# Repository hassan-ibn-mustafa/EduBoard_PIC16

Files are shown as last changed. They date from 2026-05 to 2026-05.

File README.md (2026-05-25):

# EduBoard PIC16 - Trainer Kit

An educational, single-layer development board designed to simplify learning and prototyping with the Microchip PIC16F877A microcontroller. Designed entirely in KiCad, this board eliminates complexity and focuses on a modular, jumper-based routing architecture for students and electronics enthusiasts.

## 🔗 Live Interactive Preview
    
🌐 **[Click Here to View Live-Demo_&_Interactive_BOM & Project Website](https://hassan-ibn-mustafa.github.io/EduBoard_PIC16/)**

*Click the badge above to explore the live interactive web deployment and view the full layout directly in your browser!*

## 🗺️ Circuit Schematic

Here is the complete schematic diagram of the EduBoard PIC16. For a high-resolution scalable version, please check the `Docs/` directory.

<div align="center">
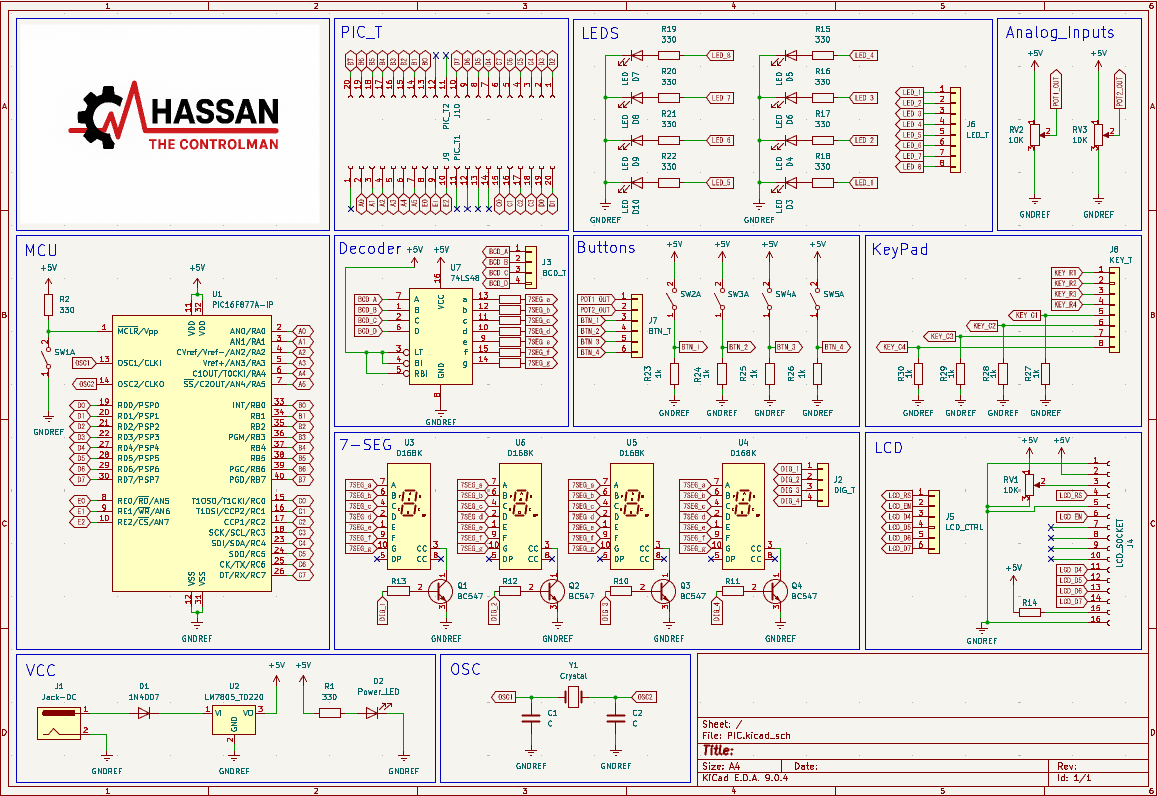
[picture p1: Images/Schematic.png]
EduBoard PIC16 Schematic Diagram
  
</div>

## 📸 3D Hardware Showcase

<div align="center">
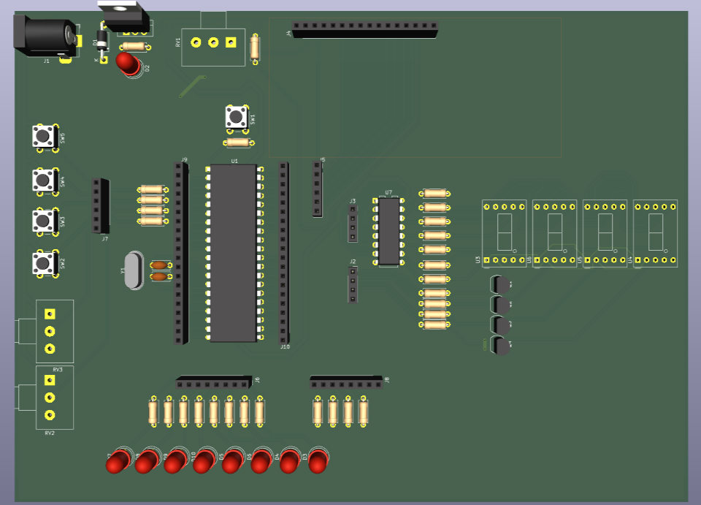
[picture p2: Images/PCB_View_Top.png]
PCB Top View
  
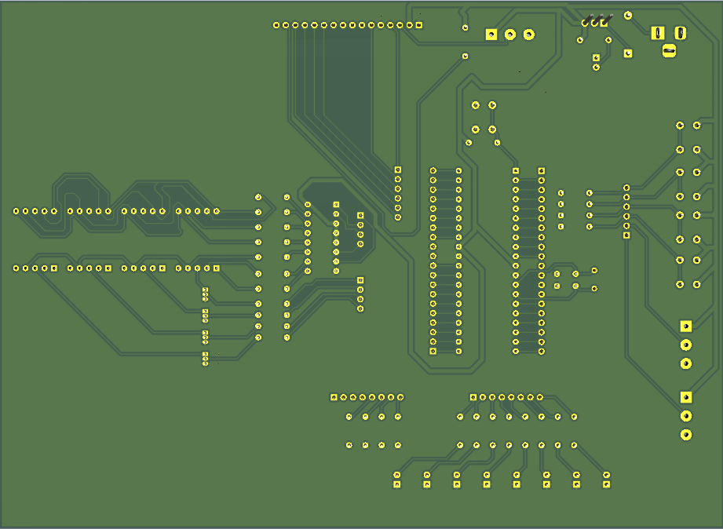
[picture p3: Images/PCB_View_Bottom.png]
PCB Bottom View
  
</div>

## 📁 Repository Structure

The repository is organized to provide easy access to documentation, source files, and manufacturing data:

* **`Docs/`**: Contains easy-to-read PDF files for quick reference without needing CAD software.
  * `Schematic.pdf`
  * `Layout_Top.pdf`
  * `Layout_Bottom.pdf`
* **`Fabrication/`**: Contains the `.zip` file with standard Gerber and Drill files. This zip file is production-ready and can be directly uploaded to any PCB manufacturer (e.g., JLCPCB, PCBWay).
* **`images/`**: Contains 3D renders and physical photos of the board.

## ⚙️ Technical Specifications

* **Microcontroller:** Microchip PIC16F877A
* **PCB Details:** Single-Layer DIY-friendly design
* **EDA Tool:** KiCad
* **Display Peripherals:** 16x2 Character LCD & 4-digit 7-segment display (multiplexed via 74LS48).
* **Power Subsystem:** LM7805 voltage regulation via DC barrel jack.
* **Routing:** 100% jumper-wire configuration using precision female headers for maximum experimental flexibility.

## 🛠️ Fabrication & Manufacturing

To manufacture this board:
1. Navigate to the `Fabrication/` directory.
2. Download the provided `.zip` file.
3. Upload the `.zip` file directly to your preferred PCB manufacturer. No further CAM processing is required.

---
*Designed & Developed by **Hassan Mustafa Hashem** - Industrial Electronics & Control Engineering.*

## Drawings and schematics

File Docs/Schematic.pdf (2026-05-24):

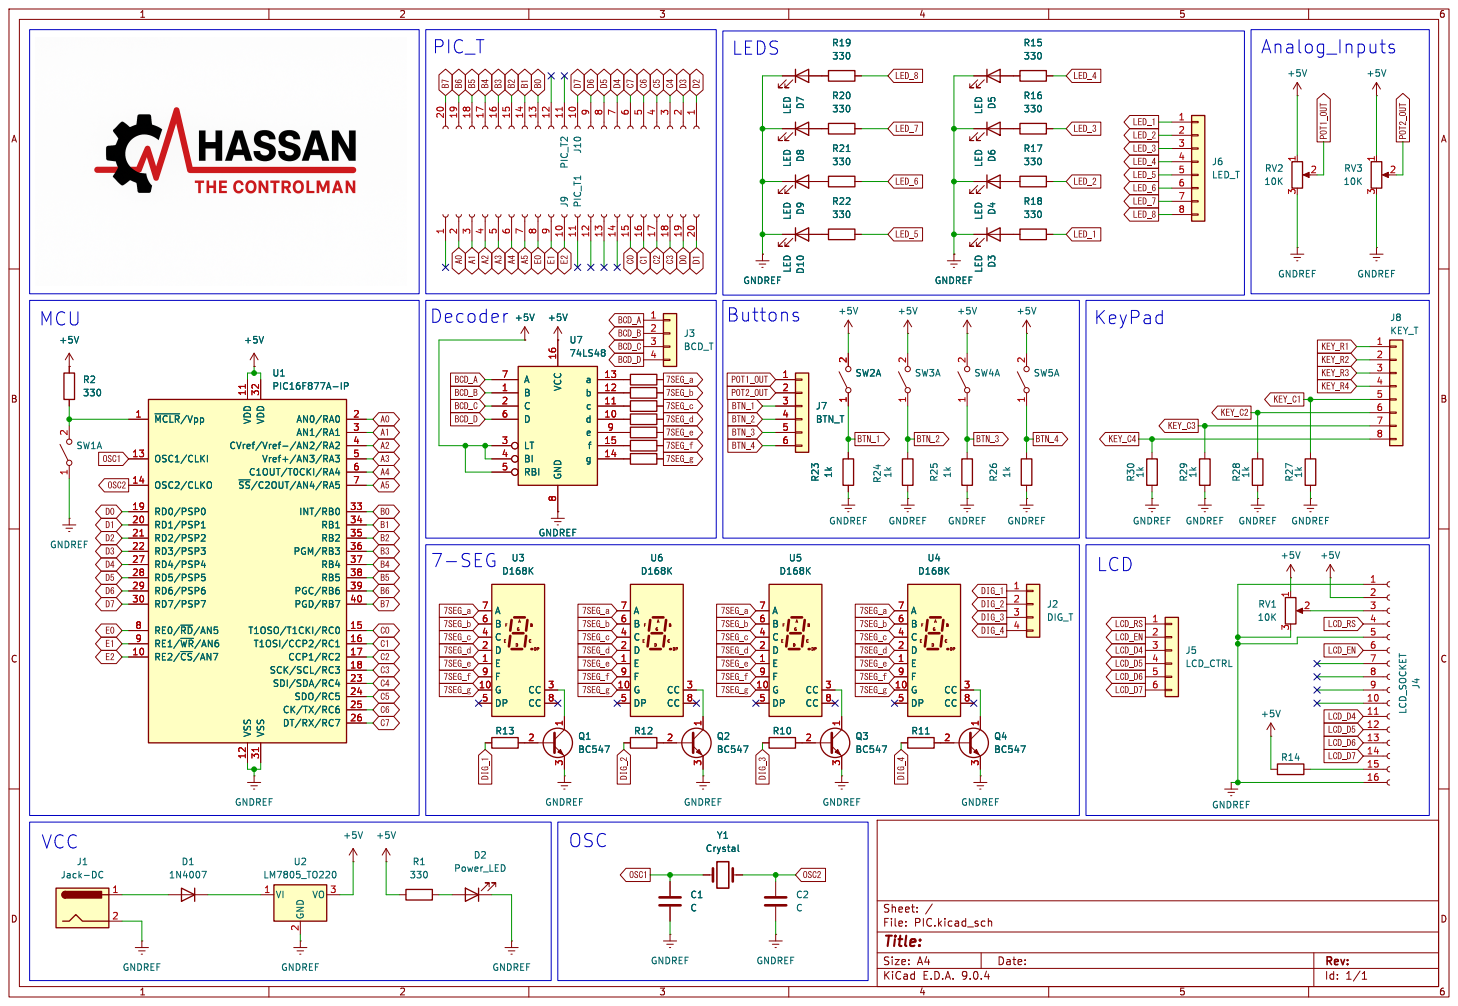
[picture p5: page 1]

1 3 Q2 BC547GNDREF GNDREF LED D10 D9 LED D8 LED D3 LED

Id: 1/1 Title: File: PIC.kicad_sch Sheet: /

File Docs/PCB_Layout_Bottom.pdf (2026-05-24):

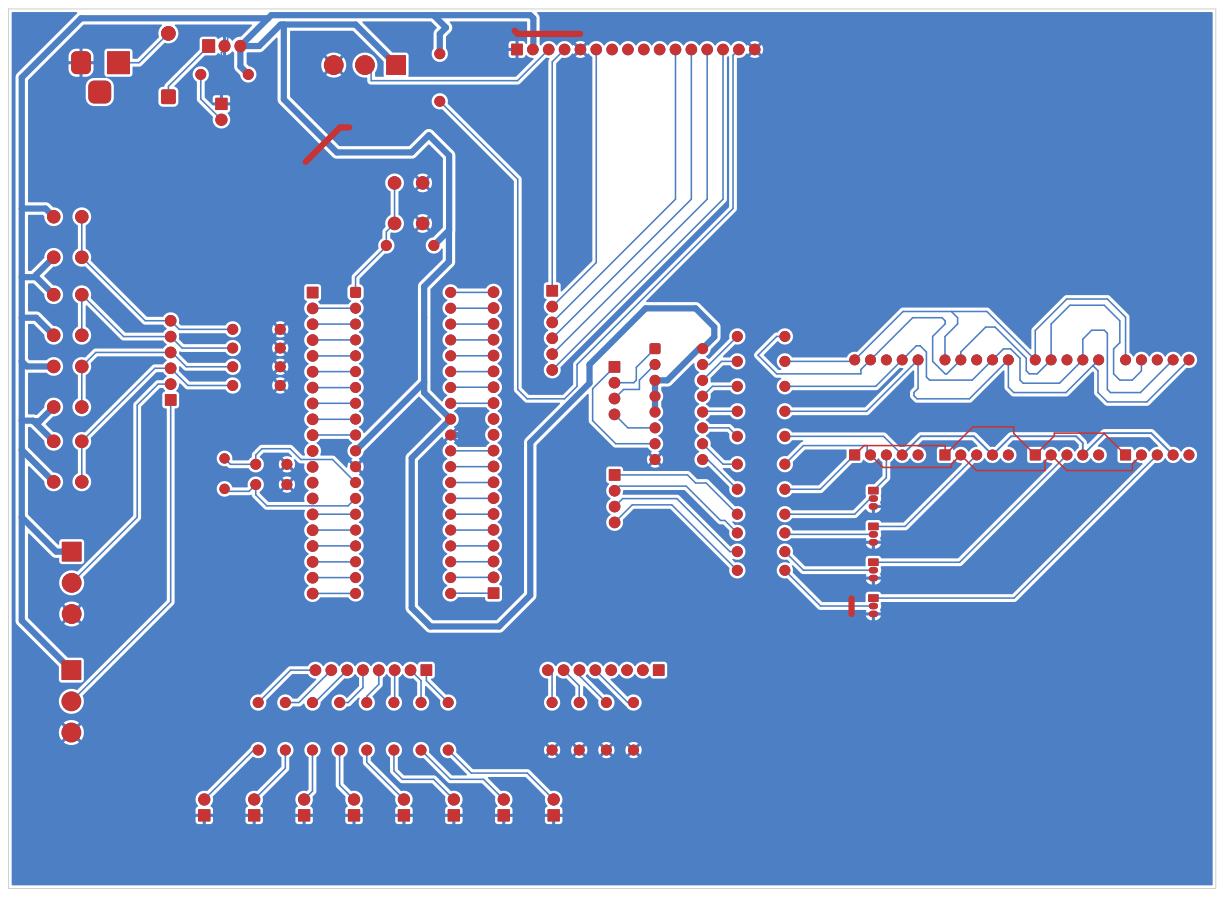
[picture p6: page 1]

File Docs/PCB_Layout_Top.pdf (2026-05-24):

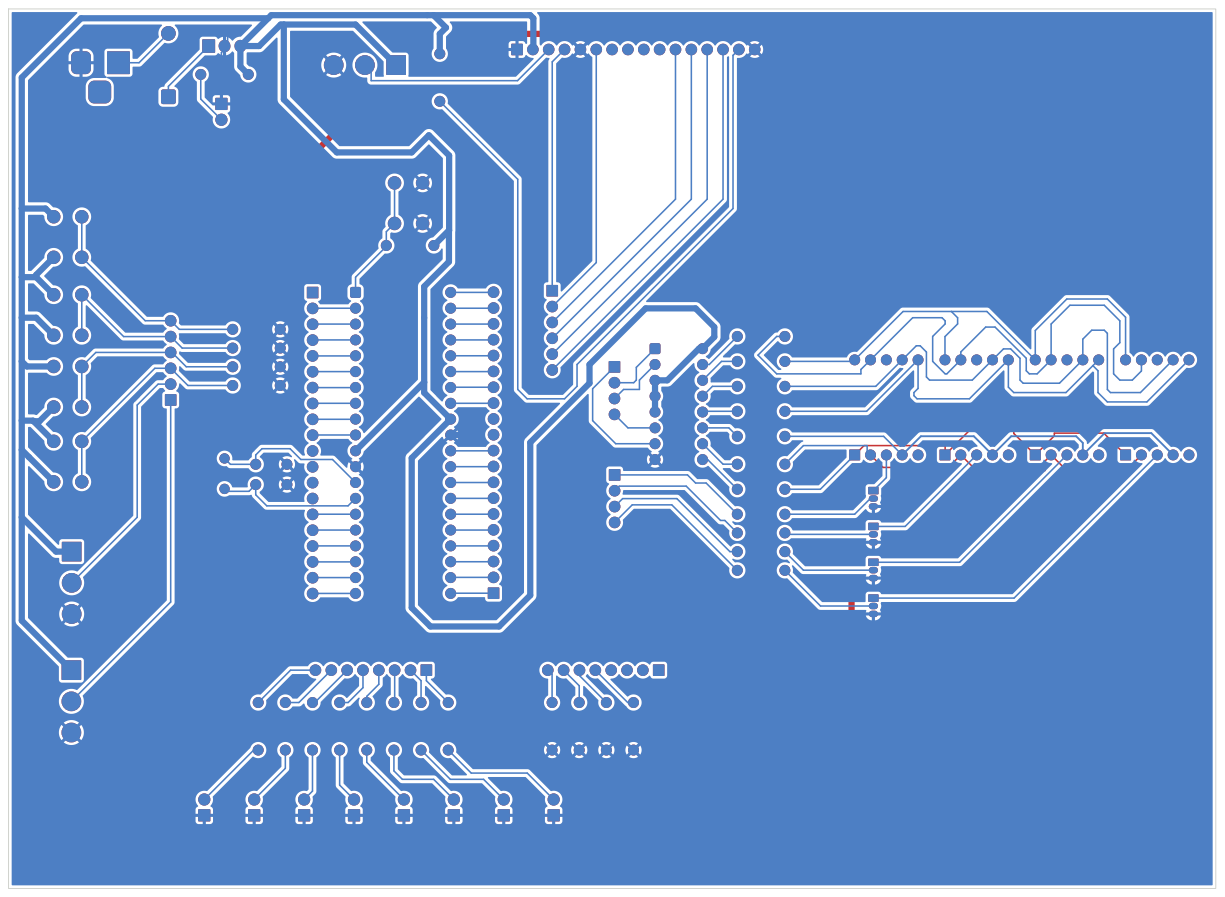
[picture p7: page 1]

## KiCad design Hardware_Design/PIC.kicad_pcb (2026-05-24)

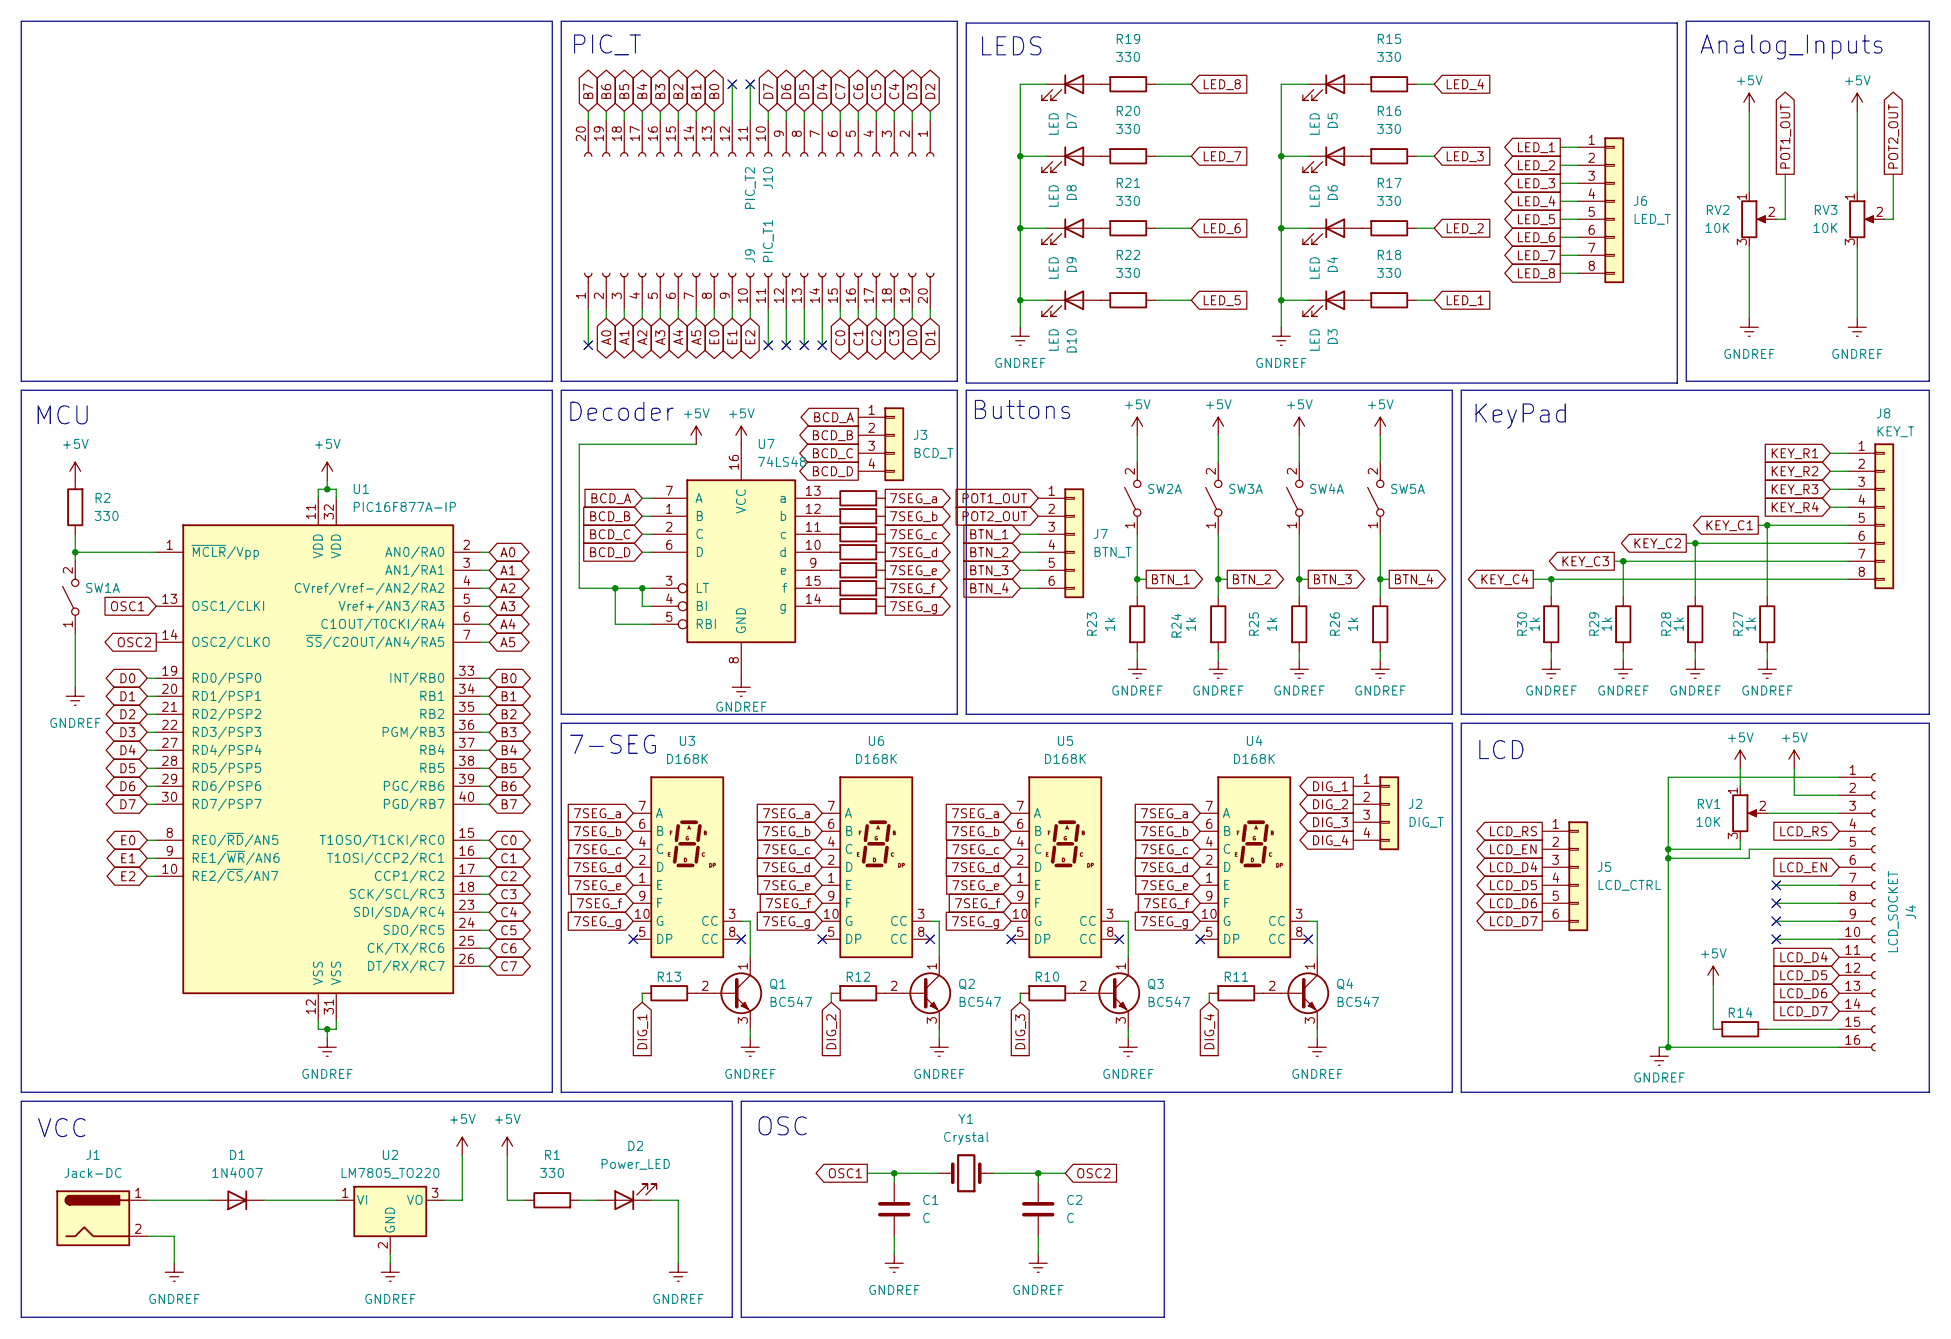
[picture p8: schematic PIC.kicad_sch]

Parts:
C1, C2: C; C_Disc_D5.0mm_W2.5mm_P5.00mm
D1: 1N4007; D_DO-41_SOD81_P10.16mm_Horizontal
D2: Power_LED; LED_D5.0mm
D3, D4, D5, D6, D7, D8, D9, D10: LED; LED_D5.0mm
J1: Jack-DC; BarrelJack_Horizontal
J2: DIG_T; PinSocket_1x04_P2.54mm_Vertical
J3: BCD_T; PinSocket_1x04_P2.54mm_Vertical
J4: LCD_SOCKET; PinSocket_1x16_P2.54mm_Vertical
J5: LCD_CTRL; PinSocket_1x06_P2.54mm_Vertical
J6: LED_T; PinSocket_1x08_P2.54mm_Vertical
J7: BTN_T; PinSocket_1x06_P2.54mm_Vertical
J8: KEY_T; PinSocket_1x08_P2.54mm_Vertical
J9: PIC_T1; PinSocket_1x20_P2.54mm_Vertical
J10: PIC_T2; PinSocket_1x20_P2.54mm_Vertical
Q1, Q2, Q3, Q4: BC547; TO-92_Inline
R1, R2, R3, R4, R5, R6, R7, R8, R9, R15, R16, R17, R18, R19, R20, R21, R22: 330; R_Axial_DIN0207_L6.3mm_D2.5mm_P7.62mm_Horizontal
R10, R11, R12, R13, R14: 1K; R_Axial_DIN0207_L6.3mm_D2.5mm_P7.62mm_Horizontal
R23, R24, R25, R26, R27, R28, R29, R30: 1k; R_Axial_DIN0207_L6.3mm_D2.5mm_P7.62mm_Horizontal
RV1, RV2, RV3: 10K; Potentiometer_Alps_RK163_Single_Horizontal
SW1, SW2, SW3, SW4, SW5: SW_DPST_x2; SW_PUSH_6mm
U1: PIC16F877A-IP; DIP-40_W15.24mm
U2: LM7805_TO220; TO-220-3_Vertical
U3, U4, U5, U6: D168K; D1X8K
U7: 74LS48; DIP-16_W7.62mm
Y1: Crystal; Crystal_HC49-4H_Vertical

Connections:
7SEG_a: R3.2, U3.7 (A), U4.7 (A), U5.7 (A), U6.7 (A)
7SEG_b: R4.1, U3.6 (B), U4.6 (B), U5.6 (B), U6.6 (B)
7SEG_c: R5.2, U3.4 (C), U4.4 (C), U5.4 (C), U6.4 (C)
7SEG_d: R6.1, U3.2 (D), U4.2 (D), U5.2 (D), U6.2 (D)
7SEG_e: R7.2, U3.1 (E), U4.1 (E), U5.1 (E), U6.1 (E)
7SEG_f: R8.2, U3.9 (F), U4.9 (F), U5.9 (F), U6.9 (F)
7SEG_g: R9.2, U3.10 (G), U4.10 (G), U5.10 (G), U6.10 (G)
+5V: J4.2, R1.1, R2.2, R14.2, RV1.1, RV2.1, RV3.1, SW2.2 (B), SW3.2 (B), SW4.2 (B), SW5.2 (B), U1.11 (VDD), U1.32 (VDD), U2.3 (VO), U7.3 (LT), U7.4 (BI), U7.5 (RBI), U7.16 (VCC)
A0: J9.2, U1.2 (AN0/RA0)
A1: J9.3, U1.3 (AN1/RA1)
A2: J9.4, U1.4 (CVref/Vref-/AN2/RA2)
A3: J9.5, U1.5 (Vref+/AN3/RA3)
A4: J9.6, U1.6 (C1OUT/T0CKI/RA4)
A5: J9.7, U1.7 (~SS/C2OUT/AN4/RA5)
B0: J10.13, U1.33 (INT/RB0)
B1: J10.14, U1.34 (RB1)
B2: J10.15, U1.35 (RB2)
B3: J10.16, U1.36 (PGM/RB3)
B4: J10.17, U1.37 (RB4)
B5: J10.18, U1.38 (RB5)
B6: J10.19, U1.39 (PGC/RB6)
B7: J10.20, U1.40 (PGD/RB7)
BCD_A: J3.1, U7.7 (A)
BCD_B: J3.2, U7.1 (B)
BCD_C: J3.3, U7.2 (C)
BCD_D: J3.4, U7.6 (D)
BTN_1: J7.3, R23.1, SW2.1 (A)
BTN_2: J7.4, R24.1, SW3.1 (A)
BTN_3: J7.5, R25.1, SW4.1 (A)
BTN_4: J7.6, R26.1, SW5.1 (A)
C0: J9.15, U1.15 (T1OSO/T1CKI/RC0)
C1: J9.16, U1.16 (T1OSI/CCP2/RC1)
C2: J9.17, U1.17 (CCP1/RC2)
C3: J9.18, U1.18 (SCK/SCL/RC3)
C4: J10.3, U1.23 (SDI/SDA/RC4)
C5: J10.4, U1.24 (SDO/RC5)
C6: J10.5, U1.25 (CK/TX/RC6)
C7: J10.6, U1.26 (DT/RX/RC7)
D0: J9.19, U1.19 (RD0/PSP0)
D1: J9.20, U1.20 (RD1/PSP1)
D2: J10.1, U1.21 (RD2/PSP2)
D3: J10.2, U1.22 (RD3/PSP3)
D4: J10.7, U1.27 (RD4/PSP4)
D5: J10.8, U1.28 (RD5/PSP5)
D6: J10.9, U1.29 (RD6/PSP6)
D7: J10.10, U1.30 (RD7/PSP7)
DIG_1: J2.1, R13.2
DIG_2: J2.2, R12.2
DIG_3: J2.3, R10.2
DIG_4: J2.4, R11.2
E0: J9.8, U1.8 (RE0/~RD/AN5)
E1: J9.9, U1.9 (RE1/~WR/AN6)
E2: J9.10, U1.10 (RE2/~CS/AN7)
GNDREF: C1.2, C2.2, D2.1 (K), D3.1 (K), D4.1 (K), D5.1 (K), D6.1 (K), D7.1 (K), D8.1 (K), D9.1 (K), D10.1 (K), J1.2, J4.1, J4.5, J4.16, Q1.3 (E), Q2.3 (E), Q3.3 (E), Q4.3 (E), R23.2, R24.2, R25.2, R26.2, R27.2, R28.2, R29.2, R30.2, RV1.3, RV2.3, RV3.3, SW1.1 (A), U1.12 (VSS), U1.31 (VSS), U2.2 (GND), U7.8 (GND)
KEY_C1: J8.5, R27.1
KEY_C2: J8.6, R28.1
KEY_C3: J8.7, R29.1
KEY_C4: J8.8, R30.1
KEY_R1: J8.1
KEY_R2: J8.2
KEY_R3: J8.3
KEY_R4: J8.4
LCD_D4: J4.11, J5.3
LCD_D5: J4.12, J5.4
LCD_D6: J4.13, J5.5
LCD_D7: J4.14, J5.6
LCD_EN: J4.6, J5.2
LCD_RS: J4.4, J5.1
LED_1: J6.1, R18.1
LED_2: J6.2, R17.1
LED_3: J6.3, R16.1
LED_4: J6.4, R15.1
LED_5: J6.5, R22.1
LED_6: J6.6, R21.1
LED_7: J6.7, R20.1
LED_8: J6.8, R19.1
unnamed: D1.2 (A), J1.1
unnamed: D1.1 (K), U2.1 (VI)
unnamed: D2.2 (A), R1.2
unnamed: D3.2 (A), R18.2
unnamed: D4.2 (A), R17.2
unnamed: D5.2 (A), R15.2
unnamed: D6.2 (A), R16.2
unnamed: D7.2 (A), R19.2
unnamed: D8.2 (A), R20.2
unnamed: D9.2 (A), R21.2
unnamed: D10.2 (A), R22.2
unnamed: J4.3, RV1.2
unnamed: J4.15, R14.1
unnamed: Q1.2 (B), R13.1
unnamed: Q1.1 (C), U3.3 (CC)
unnamed: Q2.2 (B), R12.1
unnamed: Q2.1 (C), U6.3 (CC)
unnamed: Q3.2 (B), R10.1
unnamed: Q3.1 (C), U5.3 (CC)
unnamed: Q4.2 (B), R11.1
unnamed: Q4.1 (C), U4.3 (CC)
unnamed: R2.1, SW1.2 (B), U1.1 (~MCLR/Vpp)
unnamed: R3.1, U7.13 (a)
unnamed: R4.2, U7.12 (b)
unnamed: R5.1, U7.11 (c)
unnamed: R6.2, U7.10 (d)
unnamed: R7.1, U7.9 (e)
unnamed: R8.1, U7.15 (f)
unnamed: R9.1, U7.14 (g)
OSC1: C1.1, U1.13 (OSC1/CLKI), Y1.2
OSC2: C2.1, U1.14 (OSC2/CLKO), Y1.1
POT1_OUT: J7.1, RV2.2
POT2_OUT: J7.2, RV3.2

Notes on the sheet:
Analog_Inputs
Buttons
LCD
KeyPad
LEDS
PIC_T
OSC
VCC
7-SEG
Decoder
MCU

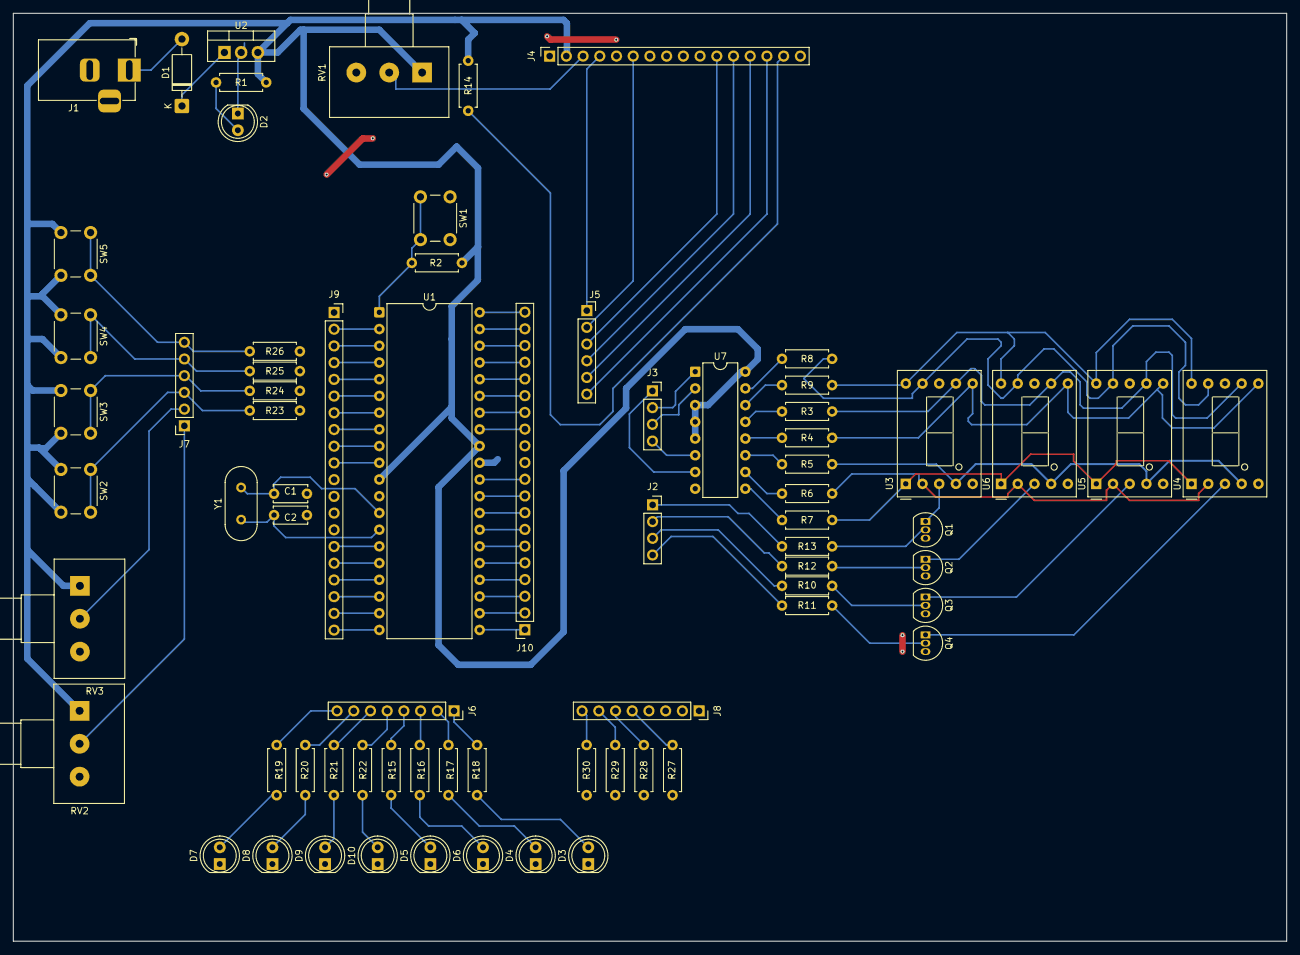
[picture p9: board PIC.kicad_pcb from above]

Board: 2 copper layers, 193.5 x 141.0 mm, 72 parts (0 on the bottom side), 105 nets.

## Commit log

2026-05-24 Correct image source path for PCB Top View
    Fix image source formatting in README.md
2026-05-24 Fix image path for schematic diagram in README
